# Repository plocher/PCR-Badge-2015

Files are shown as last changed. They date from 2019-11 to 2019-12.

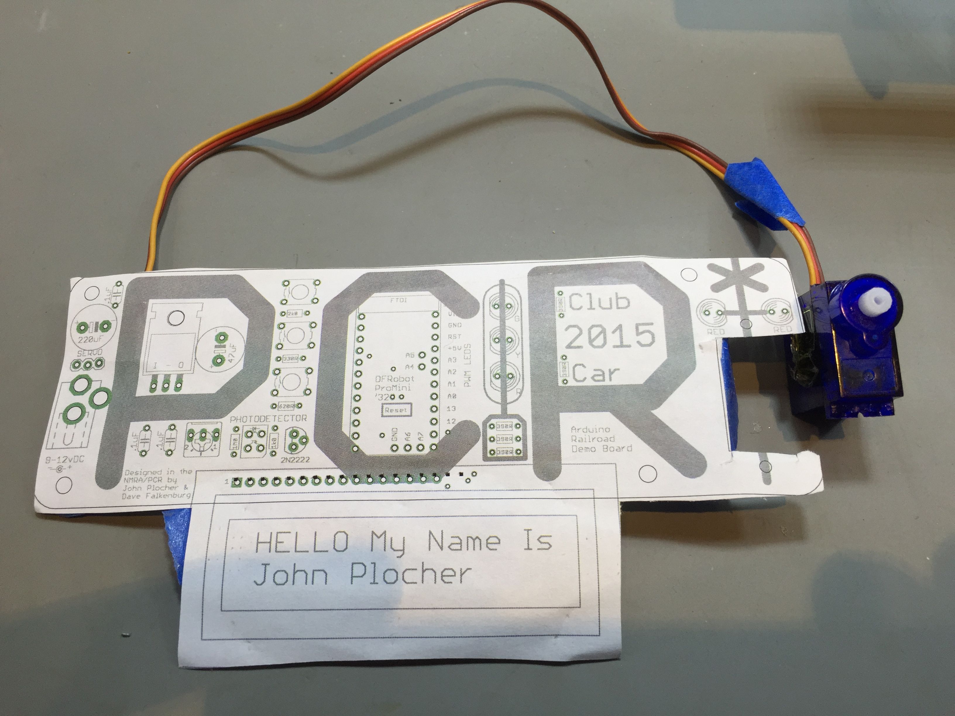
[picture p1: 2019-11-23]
IMG_0887.jpg

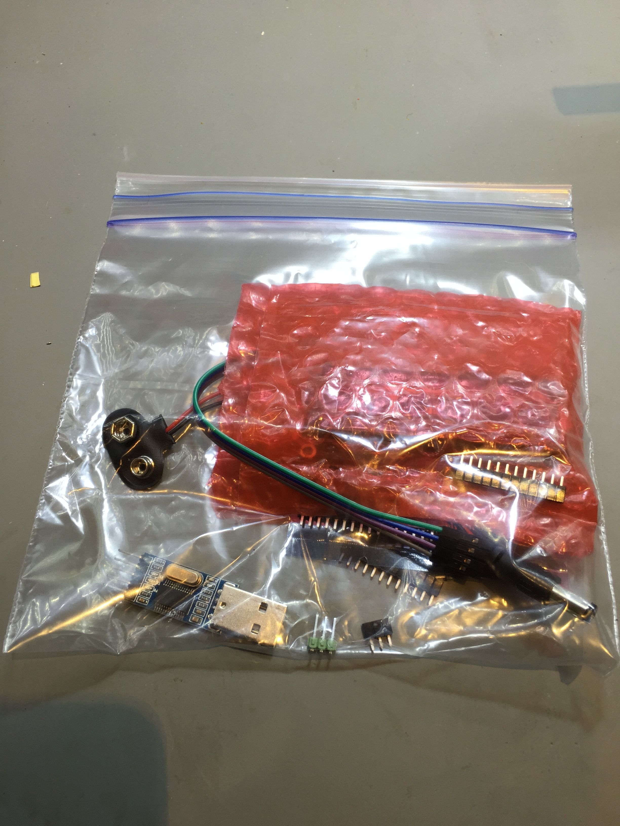
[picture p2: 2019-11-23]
IMG_0892.jpg

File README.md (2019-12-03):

# PCR-Badge-2015
## License: CERN Open Hardware Licence v1.2

PCR-Badge-2015

## PCR Club Car Convention 2015
### ‘Duino Demo Board

* [Arduino source code](https://github.com/plocher/PCRdemo2015)

Once a year, the model railroaders in Northern California and Nevada (officially, the [Pacific Coast Region](http://www.pcrnmra.org)
of the [National Model Railroad Association](http://nmra.org)) host a convention.
2015's theme was [The Club Car](http://http://www.pcrnmra.org/conv2015/) - a nod towards the many vibrant railroad clubs in the area. 

Coincidentally, the convention overlapped the Bay Area Maker Faire's time slot, which made for some very long days indeed!

Because of the juxtaposition with the Faire, [railnerd](http://railnerd.blogspot.com/) and I decided to produce an <i>assemble it yourself</i>
"badge" for the railroad convention - after all, model train buffs
are all makers of one sort or another - and getting into animations
and layout control with a 'duino is a natural progression from
controlling trains with a packet network on the rails (via [Digital
Command Control](https://en.wikipedia.org/wiki/Digital_Command_Control))...

With judicious ebay and alibaba sleuthing, along with raiding some old stockpiles and a run to
a local surplus store, we managed to produce a 30-board run with a total per-board BOM cost of about $20!
(ICStation had 1602 LCDs for ~$3.10/ea, czb6721960@ebay had Pro Mini atmega328 5V 16M's for $2.50, etc...)

The PCR demo/badge board is a foundation for experimentation and learning about ‘duino programming and model railroad applications. 

It includes
  * An Arduino-compatible “DFR-pro-mini” clone module
  * A regulated 5v power supply
  * 9v battery (good for 6-8 hours runtime…) and adapter
  * 3x pushbuttons
  * 5x LEDs, arranged as a grade crossing and a signal head
  * A servo, and
  * A 2x16 LCD display
  * I2C connector for access to expanded IO devices

Brought to you by Railnerd and SPCoast, sources for DIY model railroad electronics ideas

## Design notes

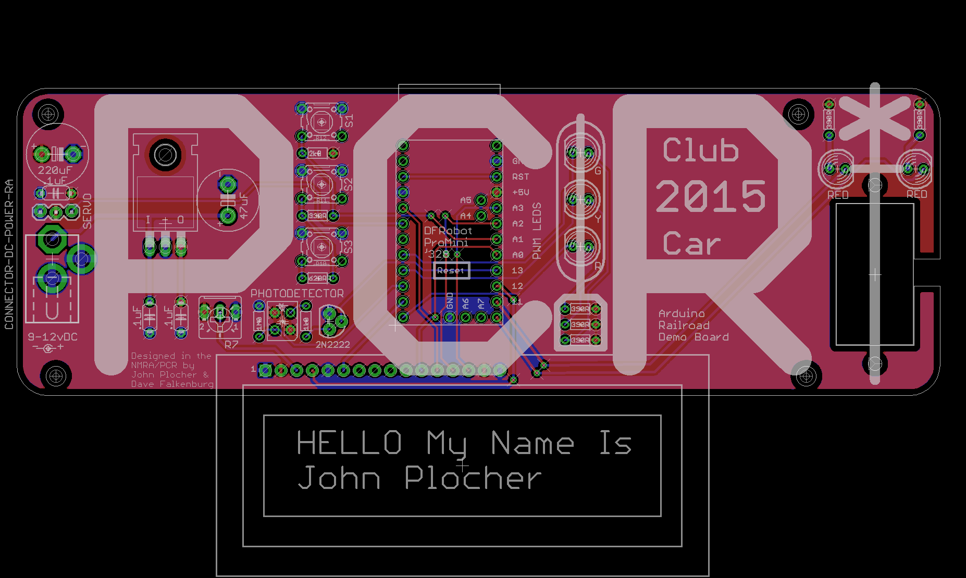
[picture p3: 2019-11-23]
Design-10-1.png

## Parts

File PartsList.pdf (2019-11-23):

Part | Value | Device
C1 | 220uF | CAP-POL-PTH-5MM
C4 | 47uF | CAP-POL-PTH-5MM
C2 | .1uF | CAP
C3 | .1uF | CAP
C5 | .1uF | CAP
R1 | 330R | Orange Orange Brown
R2 | 330R | Orange Orange Brown
R3 | 330R | Orange Orange Brown
R4 | 330R | Orange Orange Brown
R5 | 330R | Orange Orange Brown
R11 | 330R | Orange Orange Brown
R10 | 620R | Blue Red Brown
R12 | 2k0 | Red Black Red
R7 | | R-POTENTIOMETERB25U
VR | | VREG_78XX-TO-220
J4 | CONNECTOR-DC-POWER-RA | CONNECTOR-DC-POWER-RA
S1 | | SWITCH-(ON)SMALLPADS
S2 | | SWITCH-(ON)SMALLPADS
S3 | | SWITCH-(ON)SMALLPADS
S2-G | G | LEDLED5MM
S2-R | R | LEDLED5MM
S2-Y | Y | LEDLED5MM
XING1 | RED | LEDLED5MM
XING2 | RED | LEDLED5MM
SERVO | SERVO | SERVO
U1 | LCD-16X2NOHOLES | LCD-16X2NOHOLES
I2C | Mount on bottom | CONNECTOR-I2C
IRDET | PHOTODETECTOR | PHOTODETECTOR
Q4 | 2N2222 | NPN-TO92
R6 | 1k0 | RPTH-1/6W
R8 | 1M0 | RPTH-1/6W

PROMINI ARDUINO-PRO-MINIDAVESROBOT ARDUINO-PRO-MINIDAVESROBOT

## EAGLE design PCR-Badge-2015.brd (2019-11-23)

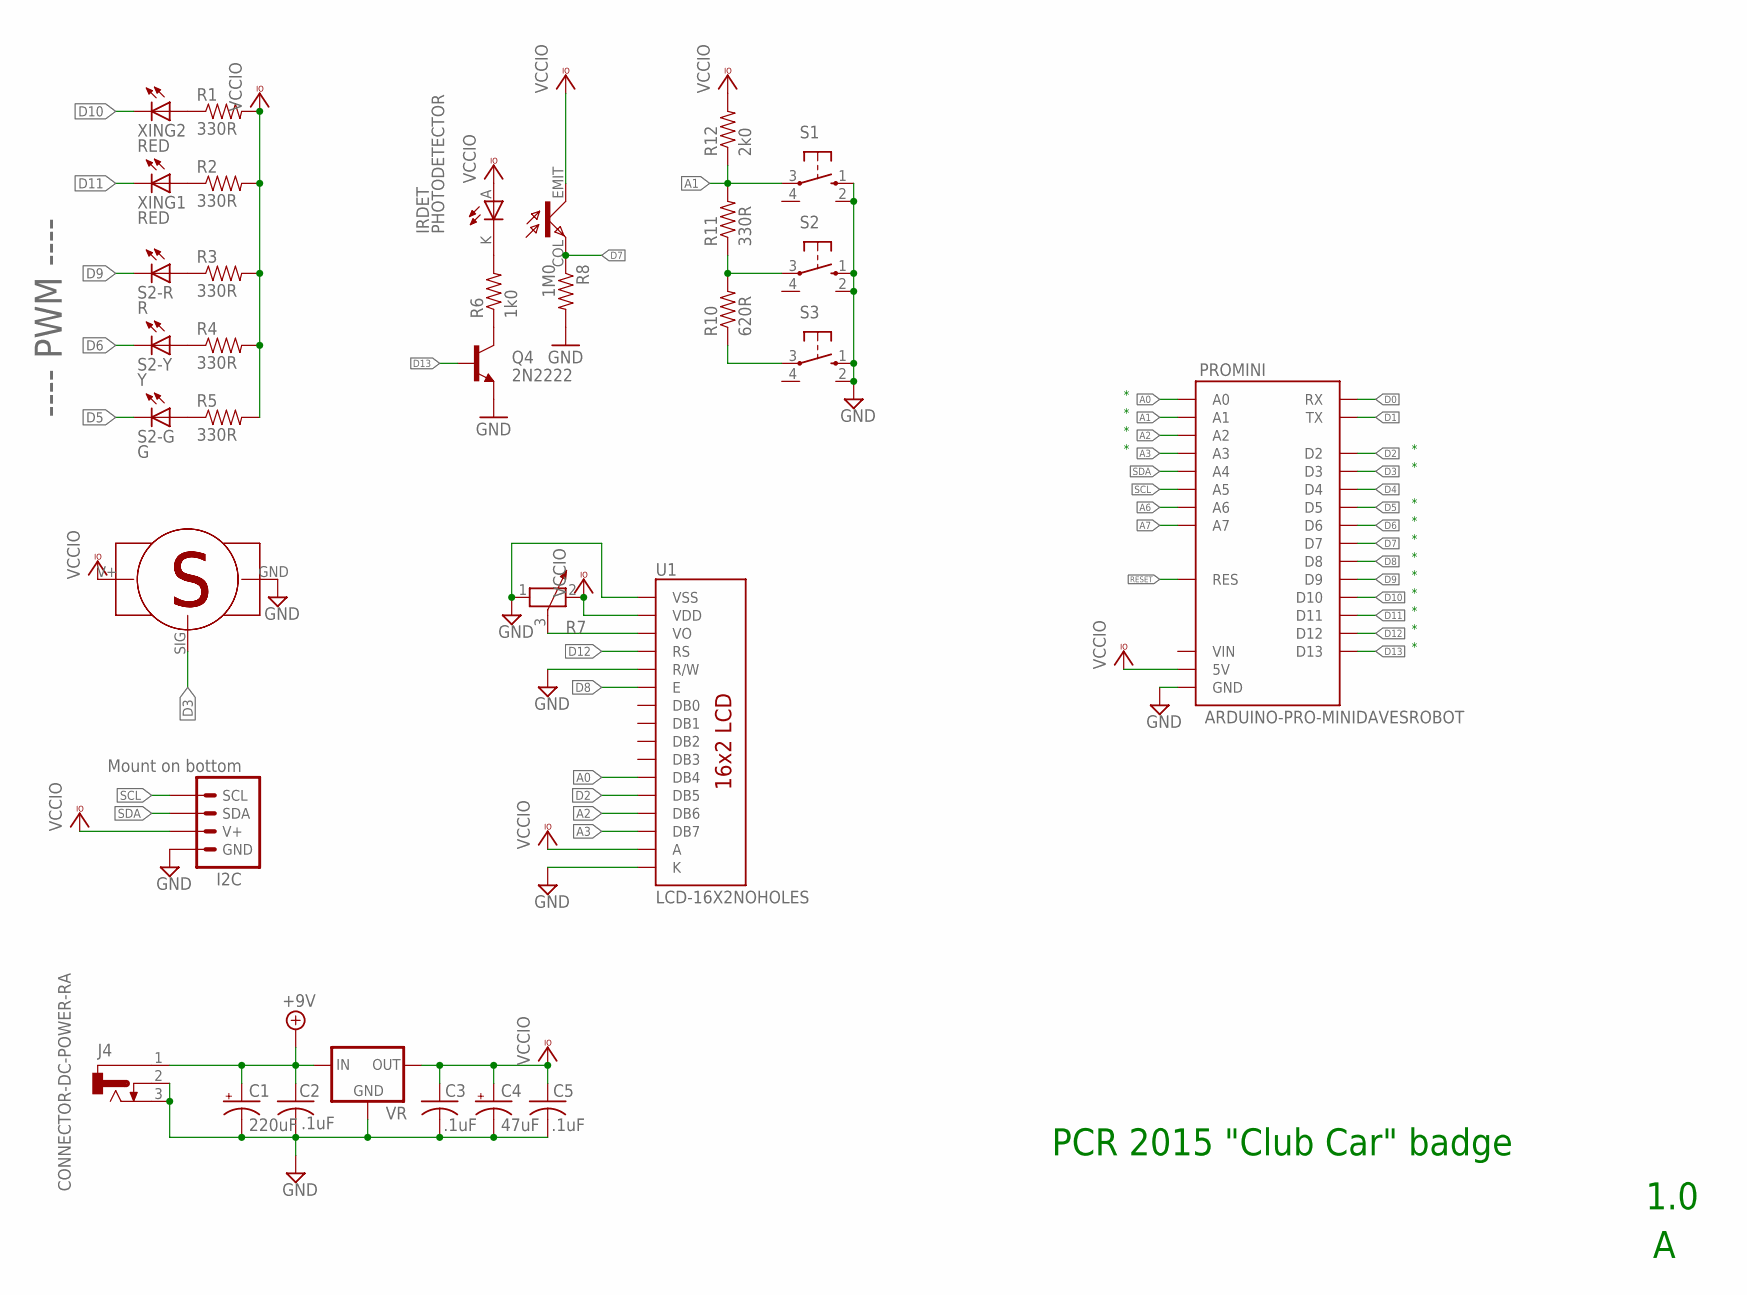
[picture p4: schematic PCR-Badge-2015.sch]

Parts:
C1: 220uF; E5-10.5
C2, C3, C5: .1uF; C050-024X044
C4: 47uF; E5-10.5
I2C: Mount on bottom; I2C
IRDET: PHOTODETECTOR; RPR220
J4: CONNECTOR-DC-POWER-RA; DCJ0202
POWER: 9-12vDC; POWER_USAGE
PROMINI: ARDUINO-PRO-MINIDAVESROBOT; ARDUINO_PRO_MINI_DAVEK
Q4: 2N2222; TO-92
R1, R2, R3, R4, R5, R11: 330R; 1/6W-RES
R6: 1k0; 1/6W-RES
R7: R-POTENTIOMETERB25U; B25U
R8: 1M0; 1/6W-RES
R10: 620R; 1/6W-RES
R12: 2k0; 1/6W-RES
S1, S2, S3: SWITCH-(ON)SMALLPADS; 4P-PTH-6.0X6.0X5.0H
S2-G: G; LED5MM
S2-R: R; LED5MM
S2-Y: Y; LED5MM
SERVO: SERVO
SERVO1: SERVO; SERVO-9G
U1: LCD-16X2NOHOLES; LCD-16X2_NOHOLES
VR: VREG_78XX-TO-220; TO-220-ALT
XING1, XING2: RED; LED5MM

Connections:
+9V: C1.+, C2.1, J4.1, VR.IN
A0: PROMINI.AD0 (A0), U1.11 (DB4)
A1: PROMINI.AD1 (A1), R11.2, R12.1, S1.3
A2: PROMINI.AD2 (A2), U1.13 (DB6)
A3: PROMINI.AD3 (A3), U1.14 (DB7)
A6: PROMINI.AD6 (A6)
A7: PROMINI.AD7 (A7)
D0: PROMINI.RX
D1: PROMINI.TX@1 (TX)
D2: PROMINI.D2, U1.12 (DB5)
D3: PROMINI.D3, SERVO.SIG (PWM)
D4: PROMINI.D4
D5: PROMINI.D5, S2-G.K (C)
D6: PROMINI.D6, S2-Y.K (C)
D7: IRDET.COL, PROMINI.D7, R8.1
D8: PROMINI.D8, U1.6 (E)
D9: PROMINI.D9, S2-R.K (C)
D10: PROMINI.D10, XING2.K (C)
D11: PROMINI.D11, XING1.K (C)
D12: PROMINI.D12, U1.4 (RS)
D13: PROMINI.D13, Q4.2 (B)
GND: C1.-, C2.2, C3.2, C4.-, C5.2, I2C.GND, J4.2, J4.3, PROMINI.GND@1 (GND), PROMINI.GND@2 (GND), PROMINI.GND@4 (GND), Q4.1 (E), R7.1, R8.2, S1.1 (S), S1.2 (S1), S2.1 (S), S2.2 (S1), S3.1 (S), S3.2 (S1), SERVO.GND, U1.1 (VSS), U1.5 (R/W), U1.16 (K), VR.GND
IRDRIVE4: Q4.3 (C), R6.1
unnamed: R1.1, XING2.A
unnamed: R2.1, XING1.A
unnamed: R3.1, S2-R.A
unnamed: R4.1, S2-Y.A
unnamed: R5.1, S2-G.A
unnamed: IRDET.K, R6.2
unnamed: R10.2, R11.1, S2.3
unnamed: R10.1, S3.3
RESET: PROMINI.RES, PROMINI.RES@1 (RES)
SCL: I2C.SCL, PROMINI.AD5 (A5)
SDA: I2C.SDA, PROMINI.AD4 (A4)
VCCIO: C3.1, C4.+, C5.1, I2C.V+, IRDET.A, IRDET.EMIT, PROMINI.5V, R1.2, R2.2, R3.2, R4.2, R5.2, R7.2, R12.2, SERVO.V+, U1.2 (VDD), U1.15 (A), VR.OUT
VO: R7.3, U1.3 (VO)

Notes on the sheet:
PCR 2015 "Club Car" badge
1.0
---- PWM ----

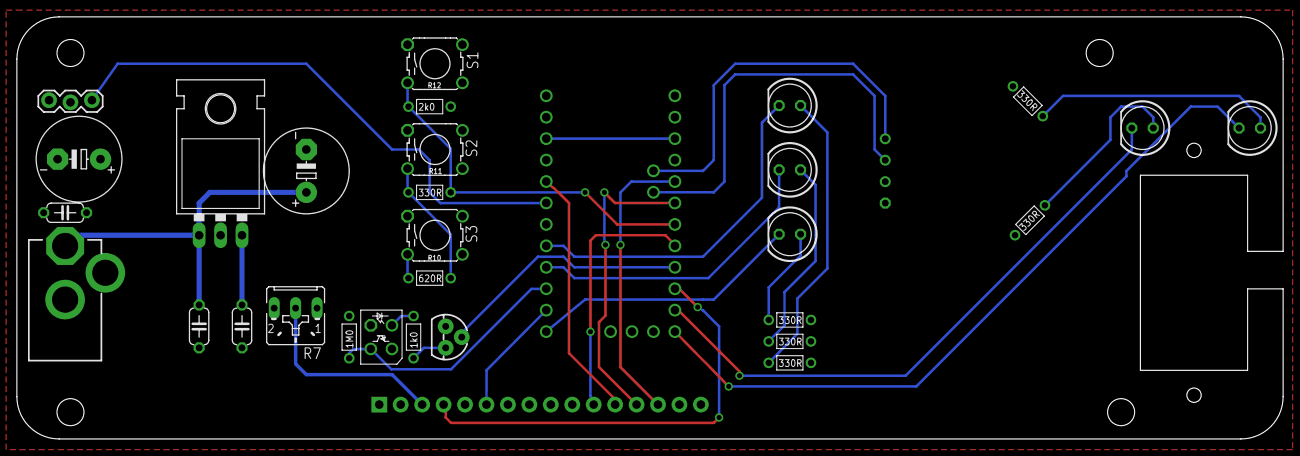
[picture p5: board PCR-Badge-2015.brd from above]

Board: 2 copper layers, 150.0 x 50.0 mm, 34 parts (1 on the bottom side), 31 nets.

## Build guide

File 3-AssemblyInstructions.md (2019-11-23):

## PCR Club Car Convention 2015 ‘Duino Demo Board

The PCR board is intended to be a foundation for experimentation and learning about ‘duino programming and model railroad applications. It provides
  *  An Arduino­compatible “DFR­pro­mini” module
  *  A regulated 5v power supply
  *  9v battery (good for only 6­8 hours runtime...) and adapter
  *  3x pushbuttons
  *  5x LEDs, arranged as a grade crossing and a signal head
  *  A servo, and
  *  A 2x16 LCD display
  *  I2C connector for access to expanded IO devices

Brought to you by SPCoast, a source for DIY model railroad electronics ideas

## Assembly instructions

### 1. Assemble the Pro-Mini

1. find two rows of 12x pins, one row of 3x pins and one row of 2x pins
2. using a breadboard to align the 12x rows, solder them to the bottom of the Pro­Mini
3. (Optional)
  *  The 3­pin row exposes the A6 and A7 Analog Input­Only pins which are not used on the demo board ­ it is OK to not install them. Installing them on the bottom makes the Pro­Mini not work in a breadboard.
  * Align the 3x row, solder it to the Pro­Mini
  *  The 2­pin row exposes the I2C signals from A4 and A5. I2C isn’t used by the demo board, though it does connect them (if present) to a 4­pin connector for your own use. As above, installing these pins on the bottom makes the Pro­Mini not fit into a breadboard, which is the reason this step is optional.
  * Insert the 2x row ­ holding it in place with a short piece of blue tape ­ and solder it carefully to the Pro­Mini
4. find the 6x row if “right angle” pins, solder it to the TOP of the Pro­Mini.
5. Set the completed Pro­Mini aside for now

### 2. Assemble the Demo Board

Working through the parts list, install

1. The capacitors (C1 & C4 are polarized ­ the long lead goes into the “+” hole)
2. The resistors ­ skip R6 & R8 (1K and 1M). Note that the 2K0 R12 (next to the top pushbutton) and the 620R R6 (near the bottom pushbutton) have different color bands than the rest (which are 330R):
  * 330R: Orange Orange Brown
  * 620R: Blue Red Brown
  * 2K0: Red Black Red
3. The potentiometer mounts under the “P”; it needs its pins gently straightened/aligned with a needlenose pliers
4. The servo connector. Use either the 3­pin right­angle or make a 3­pin straight from the extra Pro­Mini pins.
4. The voltage regulator VR1 ­ carefully bend the leads 90 degrees where they change shape.
4. The power connector ­ careful ­ the large pins/holes get hot when soldering; be sure not to burn your fingers!
4. Sw1, Sw2, Sw3 ­ you may need to clip off an unused 5th pin (the one connected to the top of the button) before you can insert them into the 4­hole footprints.
4. (The PhotoDetector feature doesn’t work, and is left unpopulated) Leave the 1M, photodiode/IRLED and 2N2222 device spots empty.
4. The female connectors (12x, 12x, 3x, 2x) for the Pro­Mini are easily aligned by plugging the actual Pro­Mini into them as they are sitting on the board; a strip of blue tape will hold everything onto the board as you turn it over to solder the pins. Solder one pin, then use your finger to push everything tight onto the board as you solder a second pin in the other corner. Once the connectors are flush and square, solder the rest of the pins. If you didn’t install the 3x and 2x pins to the Pro­Mini, you don’t need to install the mating 3x and 2x sockets either.
4. The 16 pin LCD connector. Start with one pin, ensure flush and flat, solder a second one, then the rest...
4. The LEDs ­ 2x Red for the crossbucks and 1x each Red, Yellow and Green for the Signal mast. Flat = short lead = “­”, long lead = “+”
4. The Servo. You can screw it directly to the demo board with the provided screws if desired. You can choose which “horn” to attach to the servo to match the application you will use it for. In this situation, I used the long, single ended arm to represent a crossing gate that goes up and down... Don’t attach a horn to the servo until you run the demo sketch ­ it centers the servo so you can align the horn in a pleasing orientation.

### 3. Assemble the LCD

1. Solder the 16x pin strip to the LCD, making sure it is flat and flush.

### 4. Assemble the USB Programmer

1. Find the 4­wire harness
1. Connect one end to 5.0v, TxD, RxD and GND. Make note of the colors...

### 5. Connect the pieces

1. Plug the Pro­Mini into the demo board if you haven’t already
1. Plug the servo into the 3­pin servo connector (alignment color code is printed on back of the board)
1. Plug in the LCD display
1. Connect the USB programmer to the Pro­Mini
  * 5.0v goes to VCC
  * Gnd goes to Gnd
  * TxD goes to RxD, and
  * RxD goes to TxD
1. Attach the 9v battery to the battery cable (but don’t yet plug it into the board)
1. Install (if needed) the Prolific PL2303HX drivers for your OS
  * [Windows Drivers](http://www.prolific.com.tw/US/ShowProduct.aspx?p_id=225&pcid=41)
  * [Mac Drivers](http://www.prolific.com.tw/US/ShowProduct.aspx?p_id=229&pcid=41)
  * Linux Kernel 2.4.31 and above already includes built­in drivers for PL­2303 (VID_067B&PID_2303)

### 6. Try it out
1. Load the demo sketch in your Browser and set the properties correctly
  * https://codebender.cc/sketch:112378
  * select Pro Mini (5v, 16MHz, ATmega ‘328)
  * select /dev/cu.usbserial (or whatever the Prolific 2303 enumerates as...)
2. Modify the GREETING to include your name (you may want to clone the sketch)
3. select “Run on Arduino”. When the blue bar gets more than 1⁄2 way across, press the RESET button on the Pro­Mini to tell it to run the bootloader
4. If you don’t get any errors,
  * you should see your name on the LCD,
  * The top button raises the “crossing gate”
  * The middle button turns on and off the crossing flashers
  * The bottom button lowers the gate.
5.  You can attach a horn to the servo if you want ­ lower the gate by pressing the bottom button, then attach the horn so it extends horizontally, using the remaining tiny screw that came with the servo.

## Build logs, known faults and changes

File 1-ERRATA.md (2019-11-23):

### The best laid plans ...   sigh.

We ran into two problems with this project - one easy to fix and
the other, well, not so much...

1. The grab bag batch of Red LEDs (1 pound for a dollar or some
such bargain...) was too good to be true - 20% of the LEDs turned
out to be defective - including all three I used on the initial
bring-up board.  If nothing else, it was an interesting debugging
experience and a lesson in the true cost of being cheap :-)

2. Once I got the blinking LEDs sorted out, everything else tested
out OK - except for the IR sensor.  More debugging, trace following,
scope probes - all showed that "it should be working" - except it
didn't.  Until the AHA! moment when I realized that, no matter how
many times I tried to analogRead(D7), it wouldn't work (Doh!).  This
one is all my fault - I was revising a schematic late at night,
just before the fab deadline, trying to squeeze out just one more
IO pin to do something interesting, while at the same time cleaning
up the board layout.  Obviously by moving some connections from
here to there - after all, they are just labels on the CAD screen...  
This could be "fixed" by cutting traces and running jumper
wires, which, while it would certainly make the project more
realistic, wouldn't make any friends at the convention.  I decided
to drop the feature and pull the unused parts out of the kit bags.  Sigh.

We distributed 20 kits at the show - enough for us to almost recoup
our BOM costs - and had two people spend their afternoon assembling
their kits - one of whom had never soldered before!
(his badge worked the first time, too!)

Success!

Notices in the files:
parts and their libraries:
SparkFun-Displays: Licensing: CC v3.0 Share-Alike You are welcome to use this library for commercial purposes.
